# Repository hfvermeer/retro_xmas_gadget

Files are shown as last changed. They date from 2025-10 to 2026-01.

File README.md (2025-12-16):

# retro_xmas_gadget
An ESP32S3 based retro gaming handheld running retro-go the open source retro-go, inspired by Megazoid's design on his [CrokPocket](https://www.hackster.io/megazoid/crokpocket-a0ff83).

## Story
This year my niece and nephew, who are 8 and 10 became more aware of what I do for a job as an Embedded Systems Engineer and enthousiastic hobbyist. Each time when there is a family gathering, they ask about 'my inventions', and share with me their ideas what I could invent next. Since they are so interested and we are hosting Christmas this year, I wanted to share a Christmas activity where we can assemble an invention of their own, showing them what electronics can do and giving them a nice memory.

I have stumbled on Megazoid's [design](https://www.hackster.io/megazoid/crokpocket-a0ff83) of his original CrokPocket which I really liked, but I preferred a larger screen. I also had some leftover components such as a few hundred SDHD 4gb memory cards and a stack of 1900mah batteries that I could use for this design to cut cost. And I preferred the CP2102 over the CH340G, and connectors over soldering for the display. Thus the slightly larger CrokPocket XL was born.

Even though this DIY handheld doesn't compare to many linux based emulator machines that are out there, it can't compete to something that you have build yourself. And I actually find that the keypad feels more snappy, I much prefer the shorter throw and click. Featuring the [Retro-Go](https://github.com/ducalex/retro-go) open source firmware I think it can stand on it's own, supporting many games on NES, SNES (slow), Gameboy, Sega Master System, Mega Drive, Game Gear, Colecovision, NEX PC Engine, Atari Lynx and off course, DOOM.

## Instructions

### 1. Ordering

### 2. Soldering

### 3. Flashing

### 4. Printing

### 5. Assembly

## Bill of Materials

## Release Notes

### Changes

* Version 0.9.0
    * Initial 4-layer PCB design

* Version 1.0.0
    * Correct ESP32-S3 footprint, apply keepout area to inner layers
    * Move Screw holes to corners
    * Add Load-sharing Circuit for charging

* Version 1.1.0
    * Footprint Correction for Q3
    * Change values for thermal protection resistors, R17, R23

* Known Issues
    * Reset when unplugging USB
    * Batt voltage measurement when USB plugged in
    * Guide marking for screen
    * More Decoupling for 3.3V

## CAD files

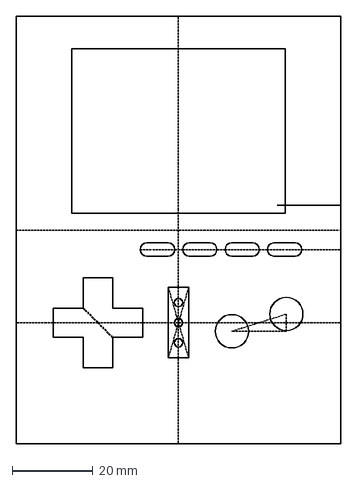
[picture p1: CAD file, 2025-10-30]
kicad/placement/Button Placement v2.dxf
80.6 x 106.0 mm

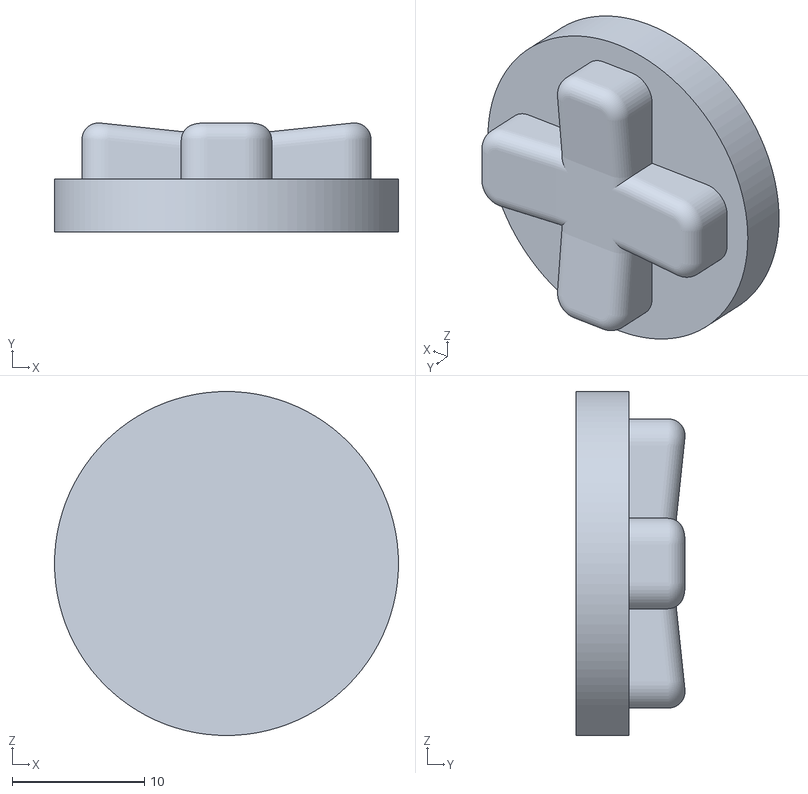
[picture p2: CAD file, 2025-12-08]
stls/v1/Thumb Button Tight.stl
26.0 x 8.25 x 26.0

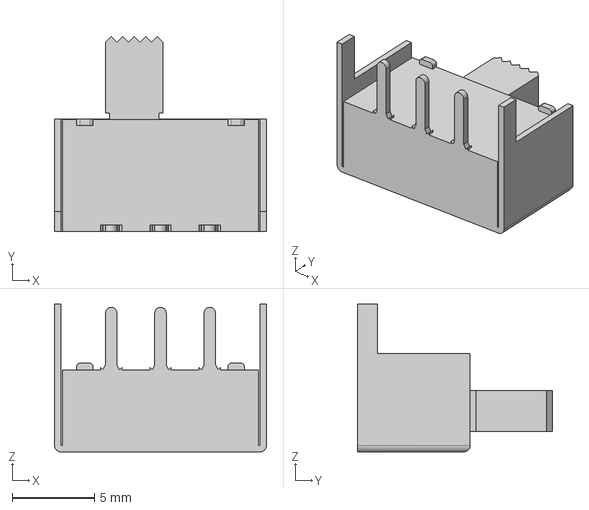
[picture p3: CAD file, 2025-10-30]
kicad/3d-models/KH-SH12F23-G6 v0.step
12.9 x 11.8 x 9.00 mm

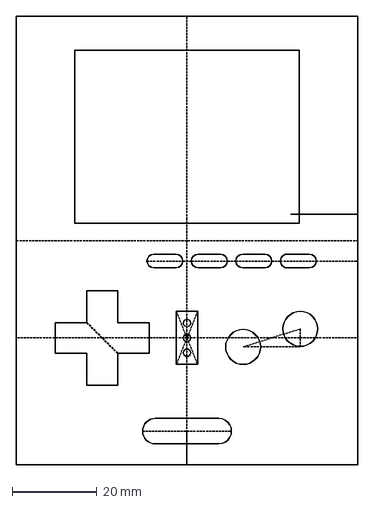
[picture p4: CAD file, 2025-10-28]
kicad/placement/Buttons.dxf
80.6 x 106.0 mm

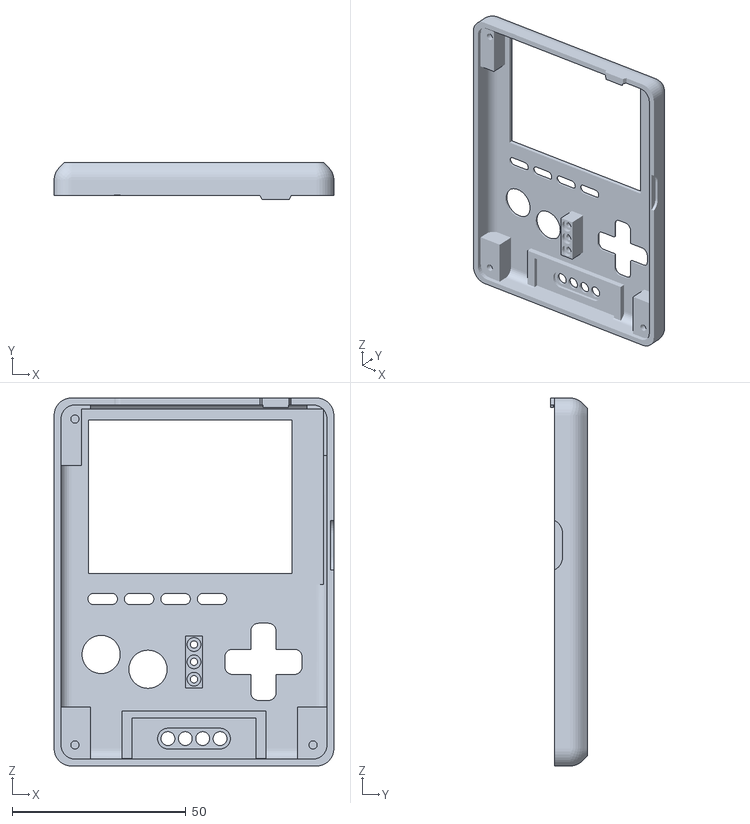
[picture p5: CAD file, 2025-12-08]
stls/v1/Front 28 inch v1.stl
80.6 x 10.8 x 106.0

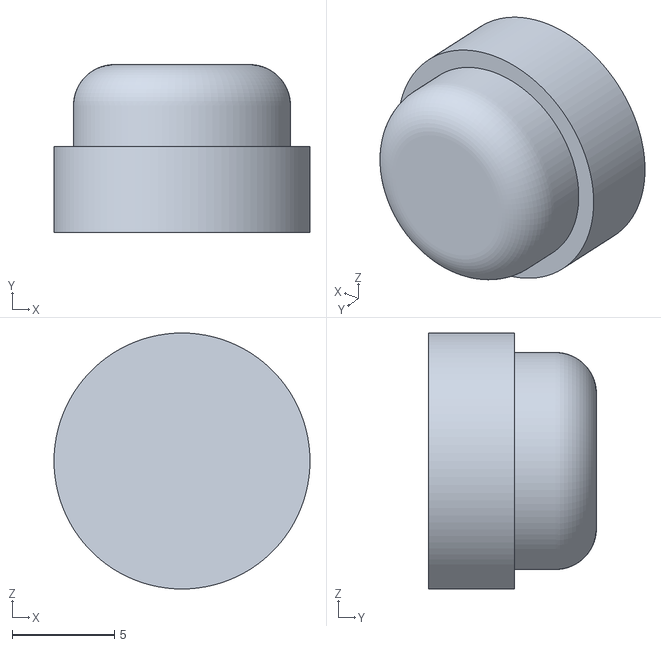
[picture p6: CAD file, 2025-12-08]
stls/v1/AB Button Tight.stl
12.5 x 8.20 x 12.5

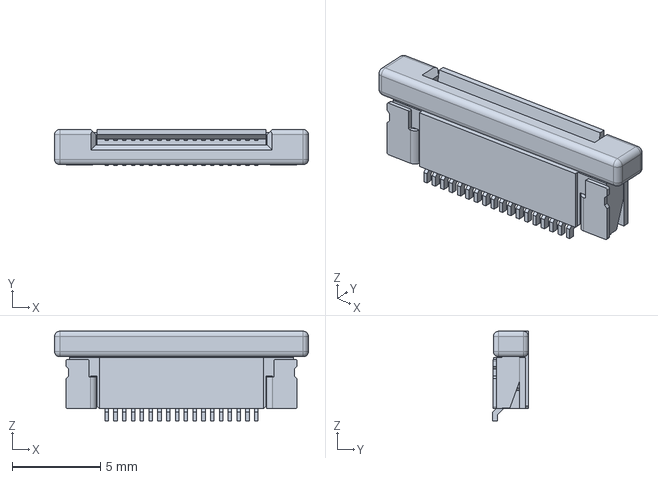
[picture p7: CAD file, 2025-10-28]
kicad/3d-models/c-1-1734839-8-c-3d.stp
14.4 x 2.05 x 5.11 mm

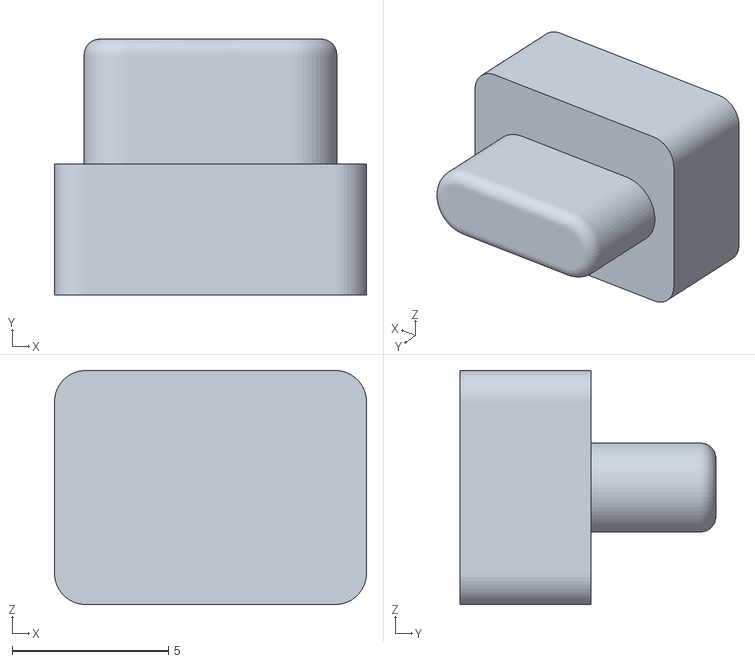
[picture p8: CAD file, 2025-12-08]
stls/v1/Function Button Tight.stl
10.00 x 8.20 x 7.50

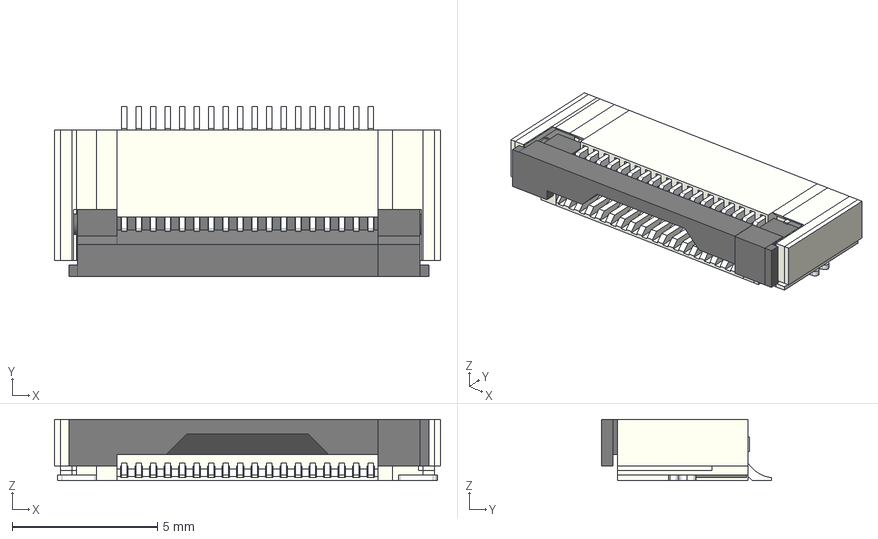
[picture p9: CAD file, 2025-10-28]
kicad/3d-models/FPC-18.stp
13.3 x 5.85 x 2.11 mm

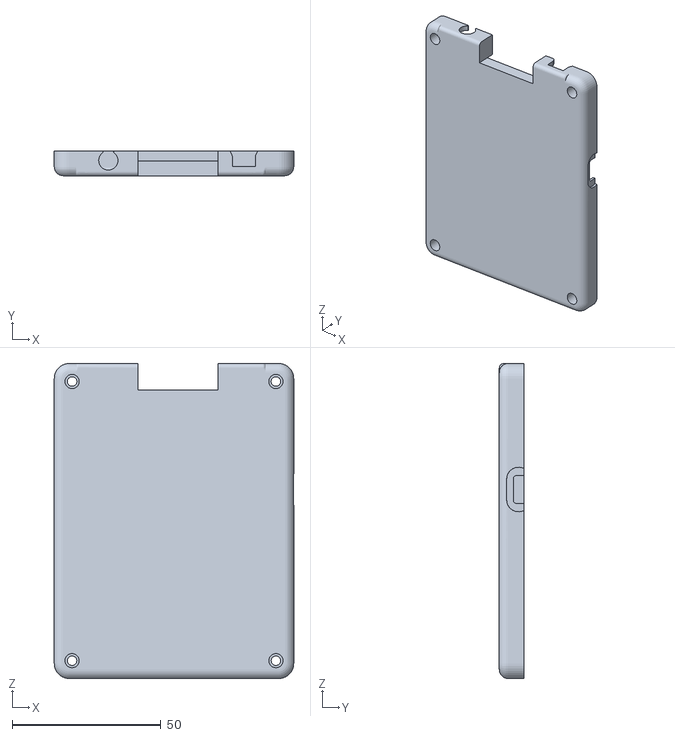
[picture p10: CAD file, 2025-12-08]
stls/v1/Back v1.stl
80.6 x 8.25 x 106.0

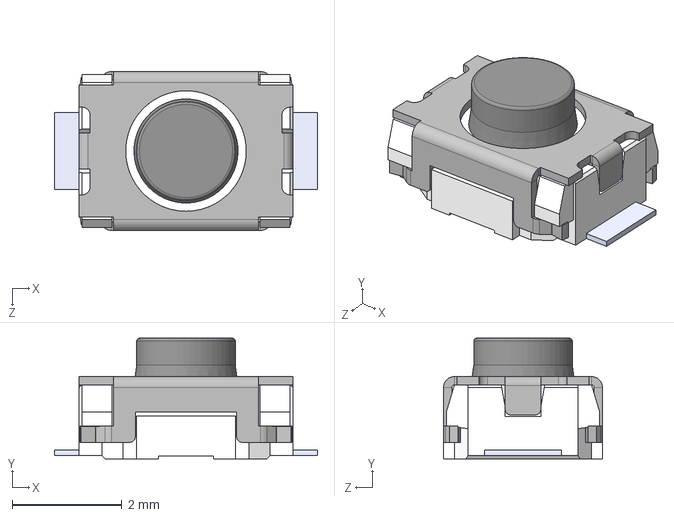
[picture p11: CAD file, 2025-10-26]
kicad/3d-models/SKRKAHE020--3DModel-STEP-56544.STEP
4.80 x 2.20 x 2.90 mm

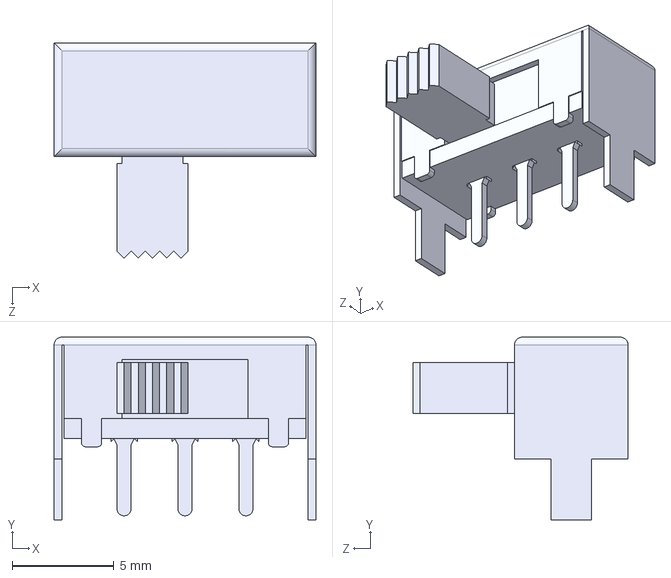
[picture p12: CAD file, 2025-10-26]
kicad/3d-models/SLW-1298856-5A-RA-N-D.STEP
12.9 x 9.00 x 10.6 mm

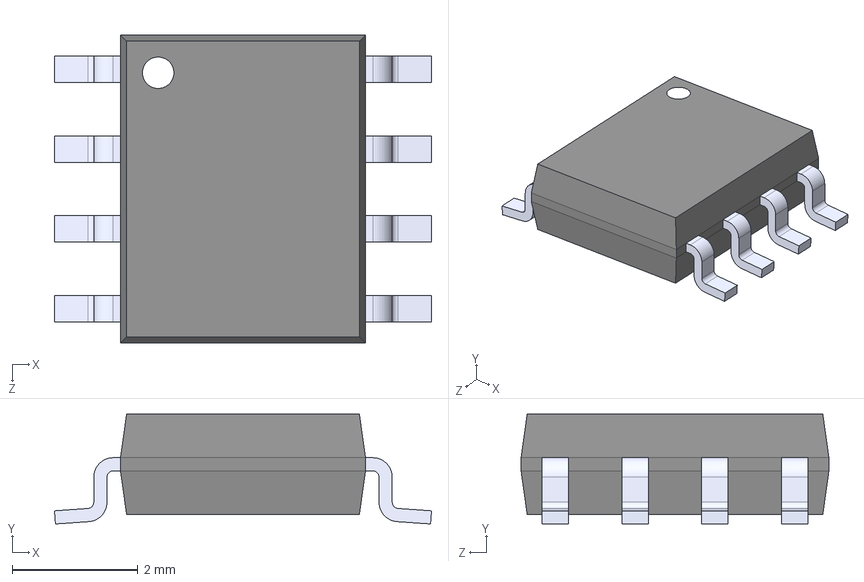
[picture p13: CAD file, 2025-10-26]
kicad/3d-models/TP4056.step
6.00 x 1.75 x 4.90 mm

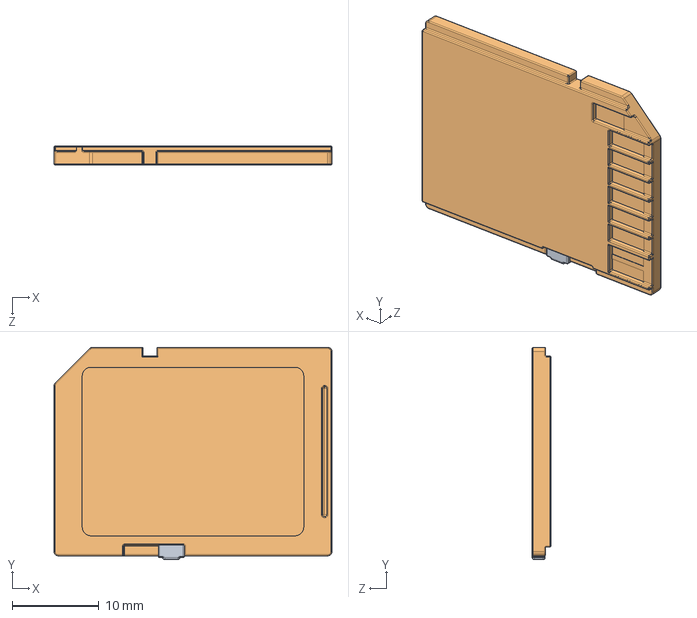
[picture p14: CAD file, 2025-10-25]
kicad/3d-models/SD Card.STEP
32.0 x 24.4 x 2.15 mm

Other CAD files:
kicad/3d-models/KB3SPRS.STEP
kicad/3d-models/10114830-10103LF.step
kicad/3d-models/10114830-10102LF.step
kicad/3d-models/2041021-4.stp

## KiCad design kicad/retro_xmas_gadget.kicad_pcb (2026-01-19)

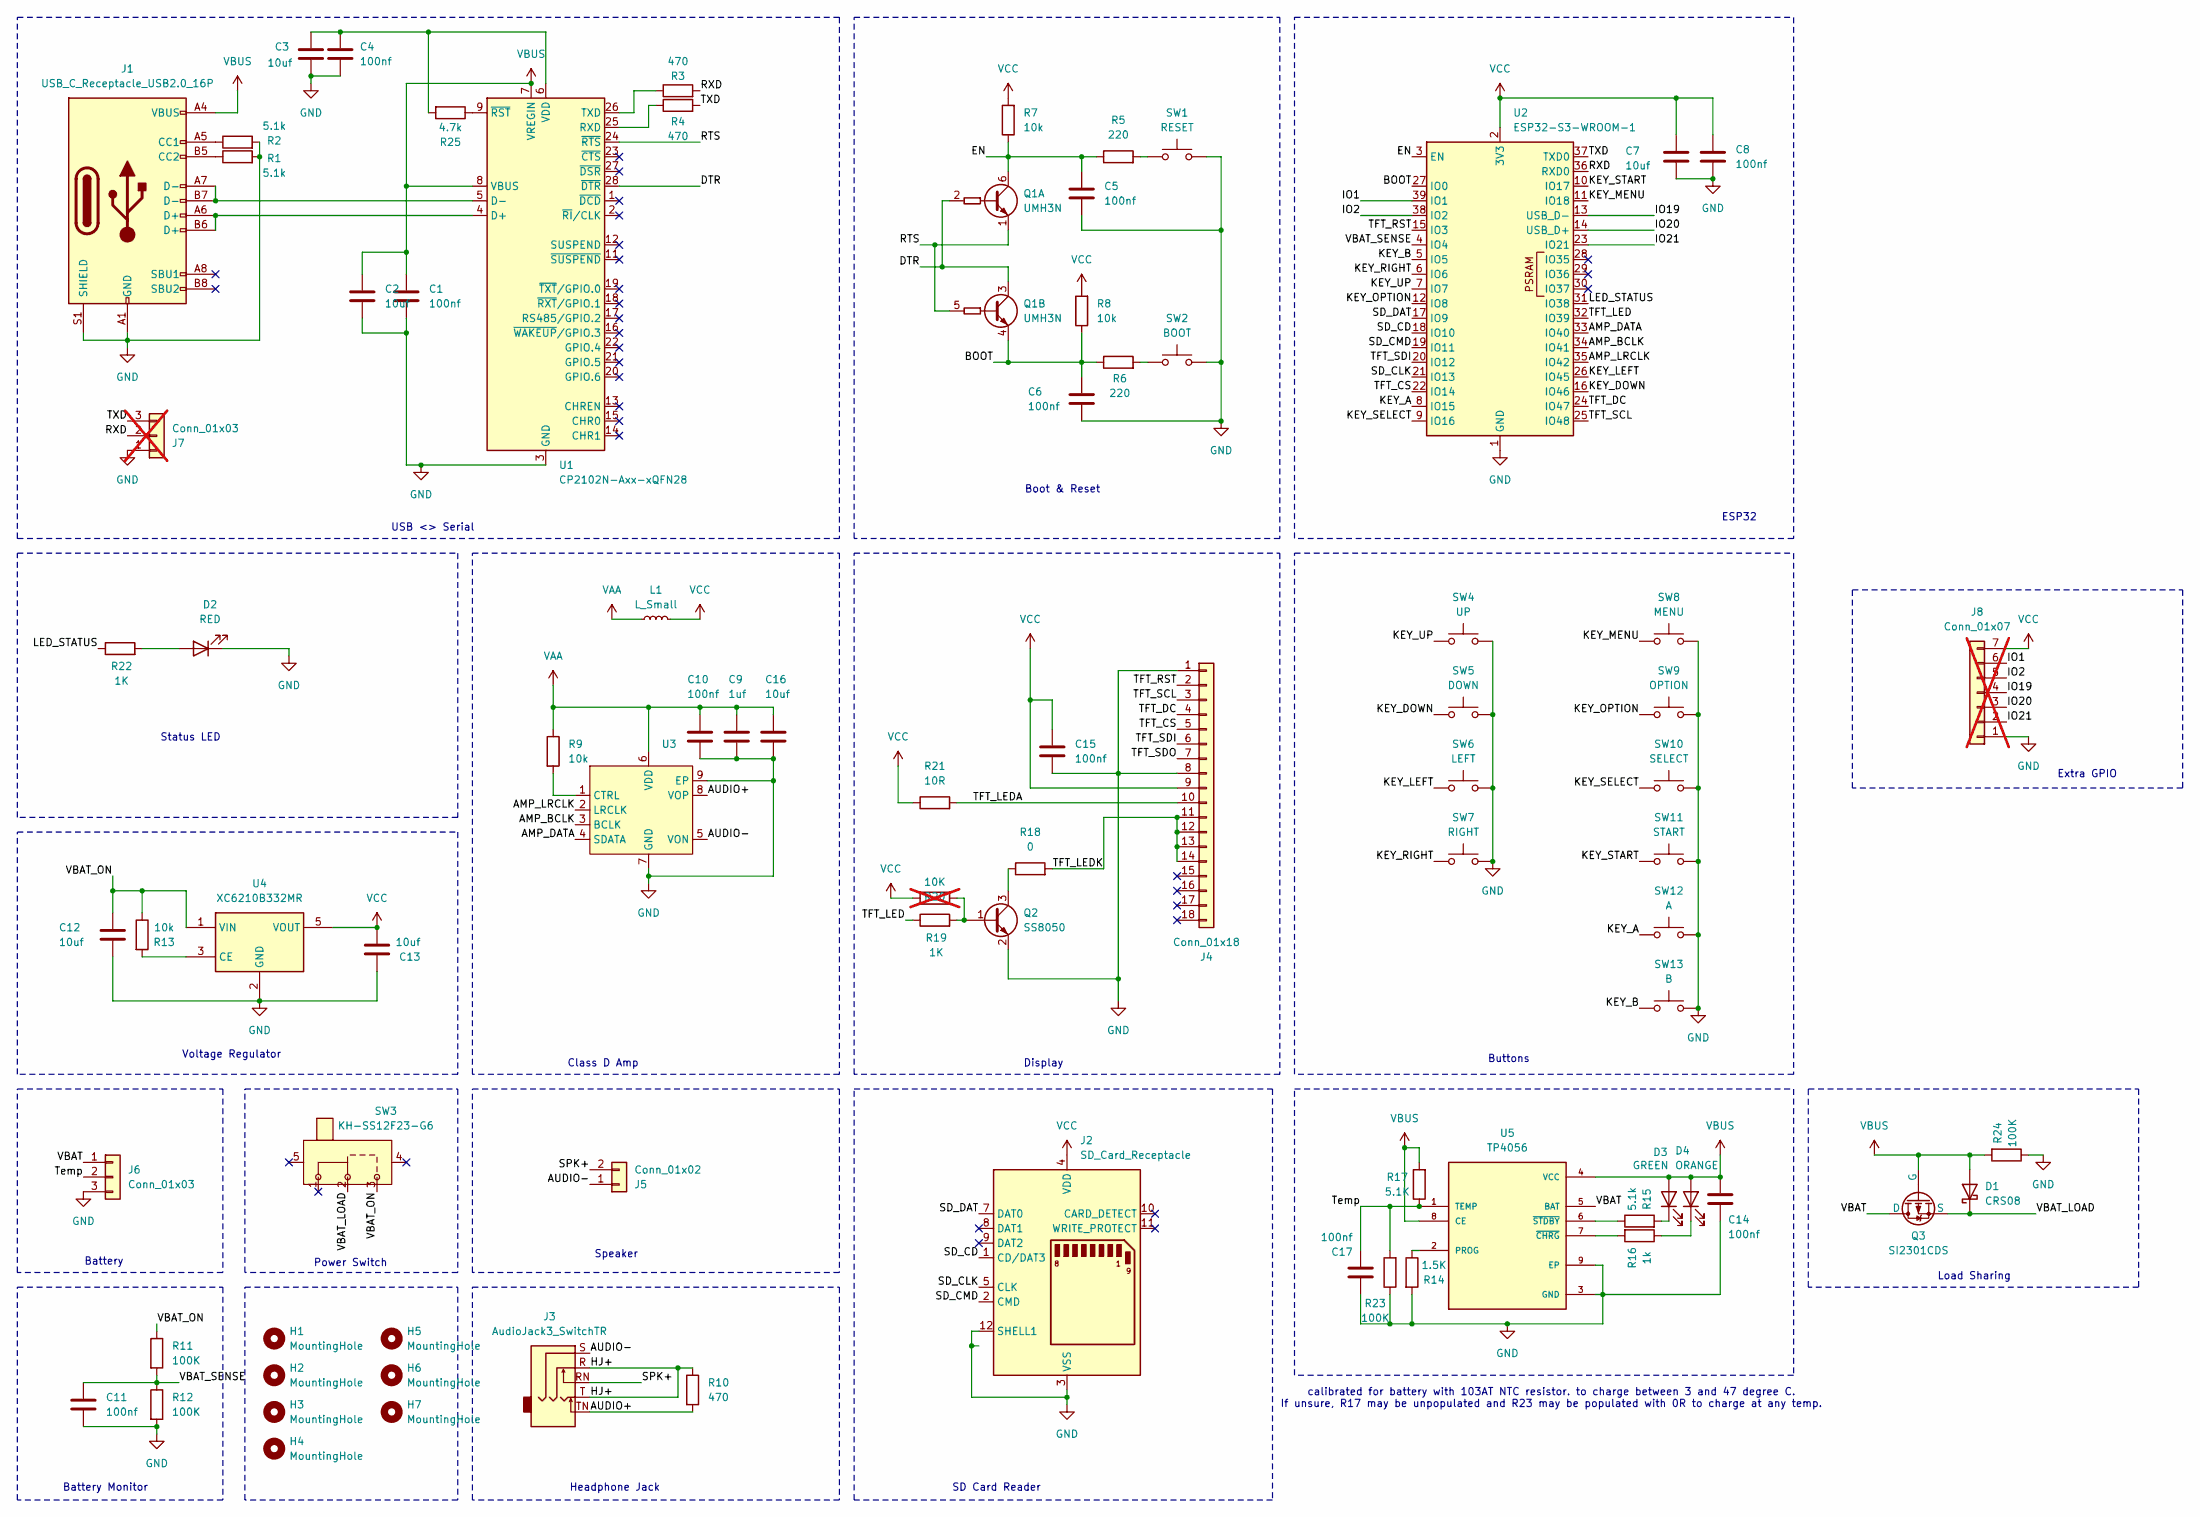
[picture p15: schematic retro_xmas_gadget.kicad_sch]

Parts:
C1, C4, C5, C6, C8, C10, C11, C14, C15, C17: 100nf; C_0603_1608Metric_Pad1.08x0.95mm_HandSolder
C2, C3, C7, C12, C13: 10uf; C_0603_1608Metric_Pad1.08x0.95mm_HandSolder
C9: 1uf; C_0603_1608Metric_Pad1.08x0.95mm_HandSolder
C16: 10uf; C_0805_2012Metric_Pad1.18x1.45mm_HandSolder
D1: CRS08; D_SOD-123
D2: RED; LED_0805_2012Metric_Pad1.15x1.40mm_HandSolder
D3: GREEN; LED_0805_2012Metric_Pad1.15x1.40mm_HandSolder
D4: ORANGE; LED_0805_2012Metric_Pad1.15x1.40mm_HandSolder
H1, H2, H3, H4: MountingHole; MountingHole_2.7mm_M2.5
H5, H6: MountingHole; MountingHole_2.5mm
H7: MountingHole; MountingHole_3.5mm
J1: USB_C_Receptacle_USB2.0_16P; USB_C_Receptacle_GCT_USB4105-xx-A_16P_TopMnt_Horizontal
J2: SD_Card_Receptacle; SD_TE_2041021
J3: AudioJack3_SwitchTR; Jack_3.5mm_Ledino_KB3SPRS_Horizontal
J4: Conn_01x18; TE_1-1734839-8_1x18-1MP_P0.5mm_Horizontal
J5: Conn_01x02; AMPHENOL_10114830-10102LF
J6: Conn_01x03; AMPHENOL_10114830-10103LF
J7: Conn_01x03; PinHeader_1x03_P2.54mm_Vertical; not fitted
J8: Conn_01x07; JST_GH_SM07B-GHS-TB_1x07-1MP_P1.25mm_Horizontal; not fitted
L1: L_Small; L_0805_2012Metric_Pad1.05x1.20mm_HandSolder
Q1: UMH3N; SOT-363_SC-70-6
Q2: SS8050; SOT-23
Q3: SI2301CDS; SOT-23_Handsoldering
R1, R2, R15: 5.1k; R_0603_1608Metric_Pad0.98x0.95mm_HandSolder
R3, R4, R10: 470; R_0603_1608Metric_Pad0.98x0.95mm_HandSolder
R5, R6: 220; R_0603_1608Metric_Pad0.98x0.95mm_HandSolder
R7, R8, R9, R13: 10k; R_0603_1608Metric_Pad0.98x0.95mm_HandSolder
R11, R12, R23, R24: 100K; R_0603_1608Metric_Pad0.98x0.95mm_HandSolder
R14: 1.5K; R_0603_1608Metric_Pad0.98x0.95mm_HandSolder
R16: 1k; R_0603_1608Metric_Pad0.98x0.95mm_HandSolder
R17: 5.1K; R_0603_1608Metric_Pad0.98x0.95mm_HandSolder
R18: 0; R_0603_1608Metric_Pad0.98x0.95mm_HandSolder
R19, R22: 1K; R_0603_1608Metric_Pad0.98x0.95mm_HandSolder
R20: 10K; R_0603_1608Metric_Pad0.98x0.95mm_HandSolder; not fitted
R21: 10R; R_0603_1608Metric_Pad0.98x0.95mm_HandSolder
R25: 4.7k; R_0603_1608Metric_Pad0.98x0.95mm_HandSolder
SW1: RESET; SW_Push_SPST_NO_Alps_SKRK
SW2: BOOT; SW_Push_SPST_NO_Alps_SKRK
SW3: KH-SS12F23-G6; SW_Slide_SPDT_Angled_CK_OS102011MA1Q
SW4: UP; SW_SPST_SKQG_WithStem
SW5: DOWN; SW_SPST_SKQG_WithStem
SW6: LEFT; SW_SPST_SKQG_WithStem
SW7: RIGHT; SW_SPST_SKQG_WithStem
SW8: MENU; SW_SPST_SKQG_WithStem
SW9: OPTION; SW_SPST_SKQG_WithStem
SW10: SELECT; SW_SPST_SKQG_WithStem
SW11: START; SW_SPST_SKQG_WithStem
SW12: A; SW_SPST_SKQG_WithStem
SW13: B; SW_SPST_SKQG_WithStem
U1: CP2102N-Axx-xQFN28; QFN-28-1EP_5x5mm_P0.5mm_EP3.35x3.35mm
U2: ESP32-S3-WROOM-1
U3: SOIC-8-1EP_3.9x4.9mm_P1.27mm_EP2.41x3.3mm_ThermalVias
U4: XC6210B332MR; SOT-23-5
U5: TP4056; SOIC-8-1EP_3.9x4.9mm_P1.27mm_EP2.41x3.3mm_ThermalVias

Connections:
/AMP_BCLK: U2.34 (IO41), U3.3 (BCLK)
/AMP_DATA: U2.33 (IO40), U3.4 (SDATA)
/AMP_LRCLK: U2.35 (IO42), U3.2 (LRCLK)
/AUDIO+: J3.TN, R10.2, U3.8 (VOP)
/AUDIO-: J3.S, J5.1, U3.5 (VON)
/BOOT: C6.1, Q1.4 (E2), R6.1, R8.1, U2.27 (IO0)
/DTR: Q1.2 (B1), Q1.3 (C2), U1.28 (~DTR)
/EN: C5.1, Q1.6 (C1), R5.1, R7.1, U2.3 (EN)
/HJ+: J3.R, J3.T, R10.1
/IO1: J8.6, U2.39 (IO1)
/IO2: J8.5, U2.38 (IO2)
/IO19: J8.4, U2.13 (USB_D-)
/IO20: J8.3, U2.14 (USB_D+)
/IO21: J8.2, U2.23 (IO21)
/KEY_A: SW12.1, U2.8 (IO15)
/KEY_B: SW13.1, U2.5 (IO5)
/KEY_DOWN: SW5.1, U2.16 (IO46)
/KEY_LEFT: SW6.1, U2.26 (IO45)
/KEY_MENU: SW8.1, U2.11 (IO18)
/KEY_OPTION: SW9.1, U2.12 (IO8)
/KEY_RIGHT: SW7.1, U2.6 (IO6)
/KEY_SELECT: SW10.1, U2.9 (IO16)
/KEY_START: SW11.1, U2.10 (IO17)
/KEY_UP: SW4.1, U2.7 (IO7)
/LED_STATUS: R22.1, U2.31 (IO38)
/RTS: Q1.1 (E1), Q1.5 (B2), U1.24 (~RTS)
/RXD: J7.2, R3.2, U2.36 (RXD0)
/SD_CD: J2.1 (CD/DAT3), U2.18 (IO10)
/SD_CLK: J2.5 (CLK), U2.21 (IO13)
/SD_CMD: J2.2 (CMD), U2.19 (IO11)
/SD_DAT: J2.7 (DAT0), U2.17 (IO9)
/SPK+: J3.RN, J5.2
/TFT_CS: J4.5, U2.22 (IO14)
/TFT_DC: J4.4, U2.24 (IO47)
/TFT_LED: R19.1, U2.32 (IO39)
/TFT_LEDA: J4.10, R21.2
/TFT_LEDK: J4.11, J4.12, J4.13, J4.14, R18.2
/TFT_RST: J4.2, U2.15 (IO3)
/TFT_SCL: J4.3, U2.25 (IO48)
/TFT_SDI: J4.6, U2.20 (IO12)
/TFT_SDO: J4.7
/TXD: J7.3, R4.2, U2.37 (TXD0)
/Temp: C17.2, J6.2, R17.1, R23.2, U5.1 (TEMP)
/VBAT: J6.1, Q3.2 (D), U5.5 (BAT)
/VBAT_LOAD: D1.1 (K), Q3.3 (S), SW3.2 (B)
/VBAT_ON: C12.2, R11.1, R13.1, SW3.3 (C), U4.1 (VIN)
/VBAT_SENSE: C11.1, R11.2, R12.1, U2.4 (IO4)
GND: C1.2, C2.2, C3.2, C4.2, C5.2, C6.2, C7.2, C8.2, C9.2, C10.2, C11.2, C12.1, C13.2, C14.2, C15.2, C16.2, C17.1, D2.1 (K), J1.A1 (GND), J1.A12 (GND), J1.B1 (GND), J1.B12 (GND), J1.S1 (SHIELD), J2.3 (VSS), J2.6 (VSS), J2.12 (SHELL1), J4.1, J4.8, J6.3, J7.1, J8.1, Q2.2 (E), R1.2, R2.2, R12.2, R14.2, R23.1, R24.1, SW1.2, SW2.2, SW4.2, SW5.2, SW6.2, SW7.2, SW8.2, SW9.2, SW10.2, SW11.2, SW12.2, SW13.2, U1.3 (GND), U1.29 (GND), U2.1 (GND), U2.40 (GND), U2.41 (GND), U3.7 (GND), U3.9 (EP), U4.2 (GND), U5.3 (GND), U5.9 (EP)
unnamed: D2.2 (A), R22.2
unnamed: D3.1 (K), R15.2
unnamed: D4.1 (K), R16.1
unnamed: J1.A5 (CC1), R2.1
unnamed: J1.B5 (CC2), R1.1
unnamed: Q2.1 (B), R19.2, R20.1
unnamed: Q2.3 (C), R18.1
unnamed: R5.2, SW1.1
unnamed: R6.2, SW2.1
unnamed: J1.A6 (D+), J1.B6 (D+), U1.4 (D+)
unnamed: J1.A7 (D-), J1.B7 (D-), U1.5 (D-)
unnamed: R4.1, U1.25 (RXD)
unnamed: R3.1, U1.26 (TXD)
unnamed: C3.1, C4.1, R25.2, U1.6 (VDD)
unnamed: R25.1, U1.9 (~RST)
unnamed: R9.2, U3.1 (CTRL)
unnamed: R13.2, U4.3 (CE)
unnamed: R14.1, U5.2 (PROG)
unnamed: R16.2, U5.7 (~CHRG)
unnamed: R15.1, U5.6 (~STDBY)
VAA: C9.1, C10.1, C16.1, L1.1, R9.1, U3.6 (VDD)
VBUS: C1.1, C2.1, C14.1, D1.2 (A), D3.2 (A), D4.2 (A), J1.A4 (VBUS), J1.A9 (VBUS), J1.B4 (VBUS), J1.B9 (VBUS), Q3.1 (G), R17.2, R24.2, U1.7 (VREGIN), U1.8 (VBUS), U5.4 (VCC), U5.8 (CE)
VCC: C7.1, C8.1, C13.1, C15.1, J2.4 (VDD), J4.9, J8.7, L1.2, R7.2, R8.2, R20.2, R21.1, U2.2 (3V3), U4.5 (VOUT)

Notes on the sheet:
Voltage Regulator
Battery Monitor
Headphone Jack
Battery
Status LED
ESP32
Load Sharing
Display
Speaker
USB <> Serial
Boot & Reset
Class D Amp
SD Card Reader
Buttons
Extra GPIO
Power Switch
calibrated for battery with 103AT NTC resistor. to charge between 3 and 47 degree C. If unsure, R17 may be unpopulated and R23 may be populated with 0R to charge at any temp.

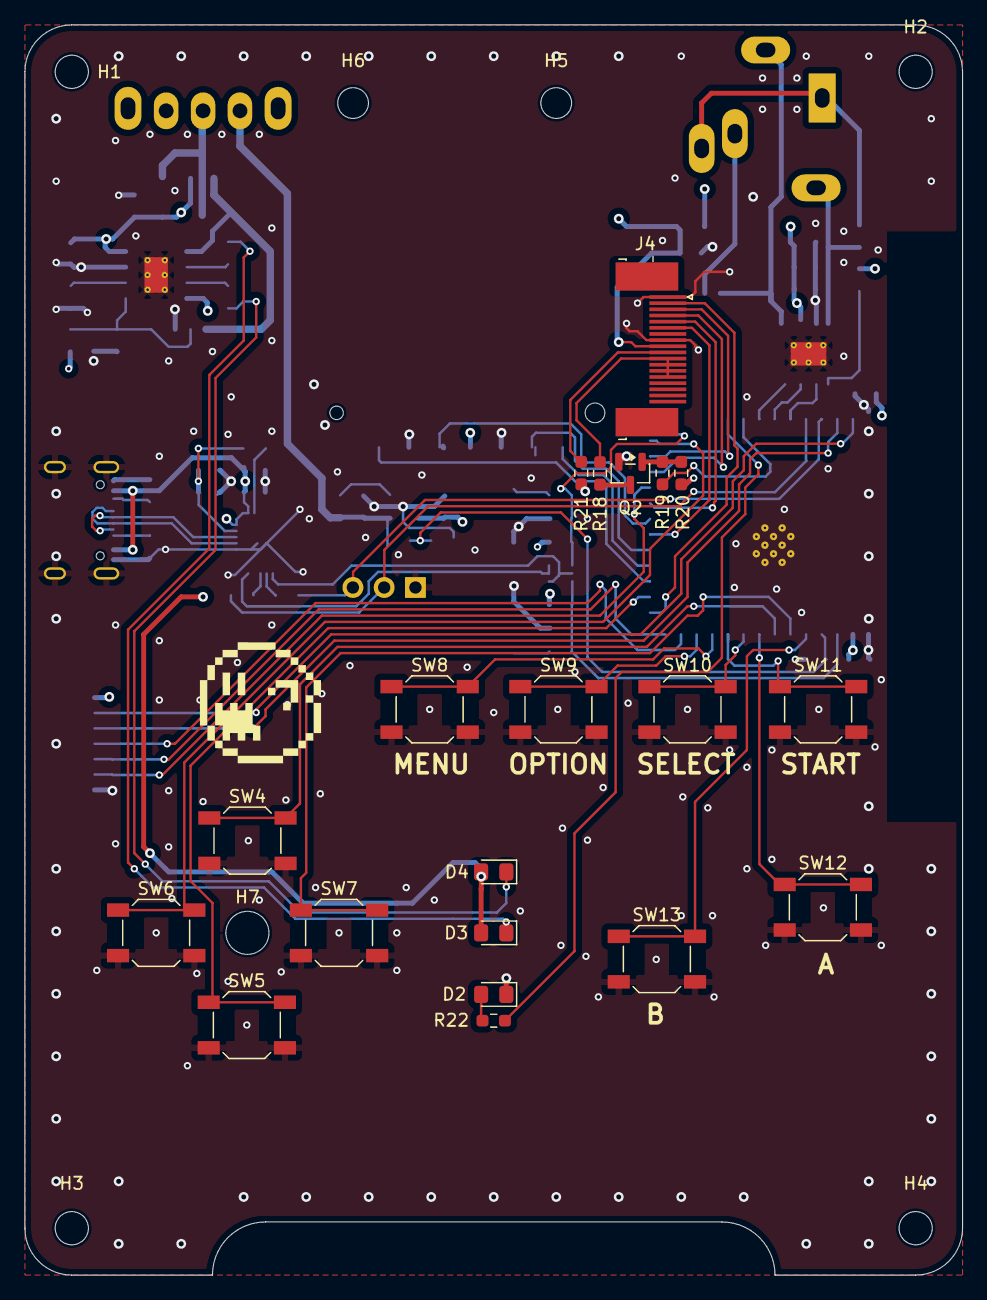
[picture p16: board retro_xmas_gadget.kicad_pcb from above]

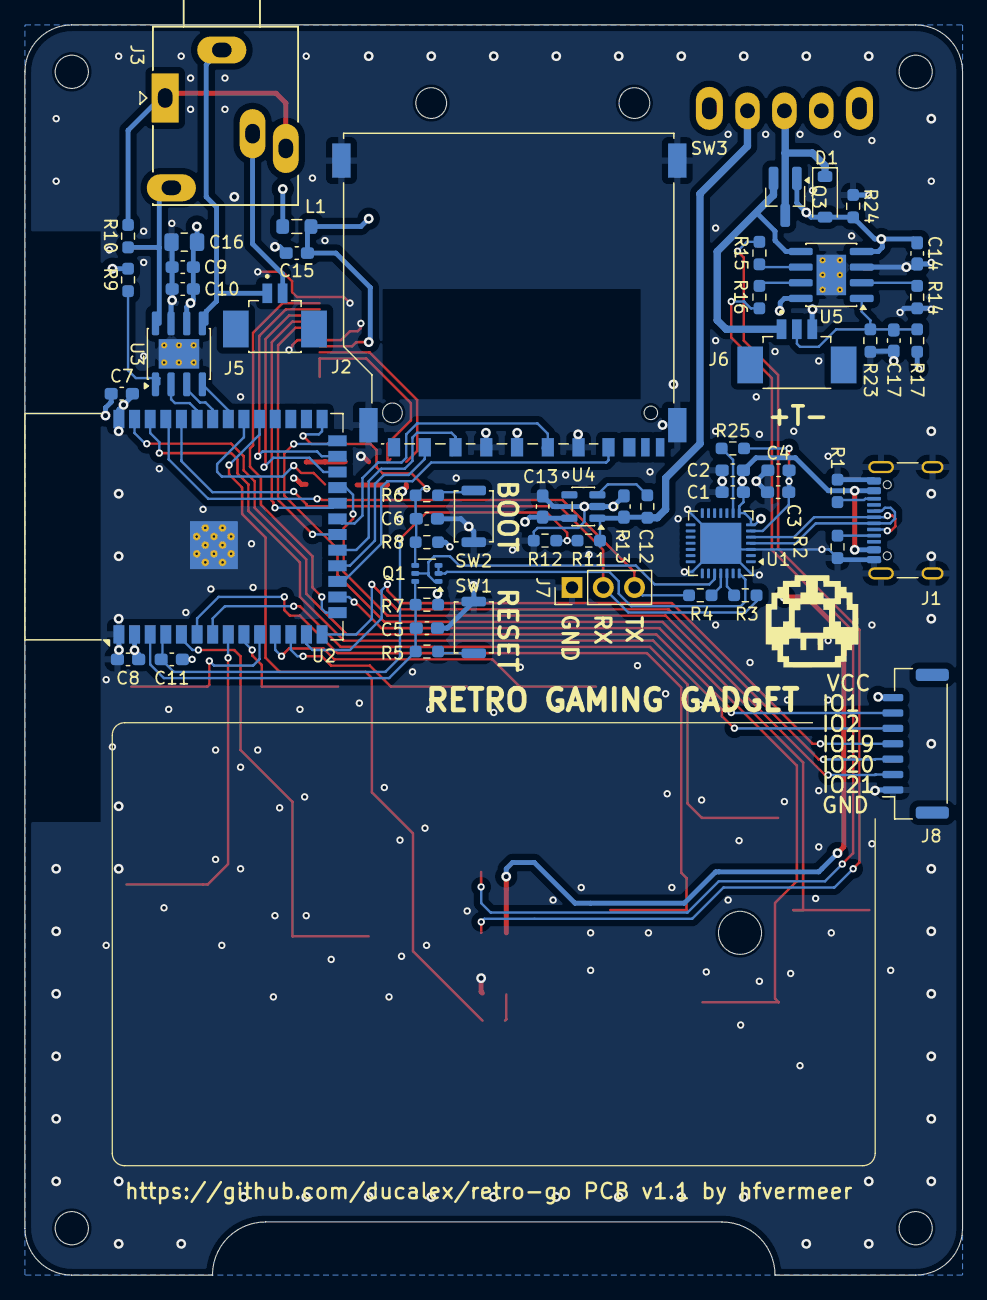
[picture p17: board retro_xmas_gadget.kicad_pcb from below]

Board: 4 copper layers, 76.2 x 101.6 mm, 83 parts (56 on the bottom side), 70 nets.

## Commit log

2025-10-25 kicad project
    [retro_xmas_gadget.kicad_pcb, retro_xmas_gadget.kicad_sch]
2025-10-25 initial schematic and board layoujt wip
    [2041021-4.stp, KB3SPRS.STEP, SD Card.STEP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]
2025-10-26 complete most of design
    [SKRKAHE020--3DModel-STEP-56544.STEP, SLW-1298856-5A-RA-N-D.STEP, TP4056.step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]
2025-10-26 initial board layout
    [retro_xmas_gadget.kicad_pcb, retro_xmas_gadget.kicad_sch]
2025-10-27 button positioning and routing
    [retro_xmas_gadget.kicad_pcb, retro_xmas_gadget.kicad_sch]
2025-10-27 moar stitching
    [retro_xmas_gadget.kicad_pcb]
2025-10-27 some DRC
    [retro_xmas_gadget.kicad_pcb]
2025-10-27 change to 4 layer pcb
    [retro_xmas_gadget.kicad_pcb, retro_xmas_gadget.kicad_sch]
2025-10-28 adjustments with 3d model
    [Buttons.dxf, FPC-18.stp, c-1-1734839-8-c-3d.stp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]
2025-10-28 baby progress
    [retro_xmas_gadget.kicad_pcb]
2025-10-28 mayor checks
    [retro_xmas_gadget.kicad_pcb, retro_xmas_gadget.kicad_sch]
2025-10-29 almost complete
    [retro_xmas_gadget.kicad_pcb, retro_xmas_gadget.kicad_sch]
2025-10-29 run down checking points
    [retro_xmas_gadget.kicad_pcb, retro_xmas_gadget.kicad_sch]
2025-10-30 final improvements and checks
    [10114830-10102LF.step, 10114830-10103LF.step, KH-SH12F23-G6 v0.step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]
2025-10-30 speaker placement
    [Button Placement v2.dxf, Front.stl, retro_xmas_gadget.kicad_pcb]
2025-10-31 final design, with decals
    [retro_xmas_gadget.kicad_pcb]
2025-11-09 3d model updates
    [retro_xmas_gadget.kicad_pcb]
2025-11-09 keep out inner layers
    [retro_xmas_gadget.kicad_pcb]
2025-11-13 improvements and corrections
    [retro_xmas_gadget.kicad_pcb, retro_xmas_gadget.kicad_sch]
2025-11-14 update charging resistor
    [retro_xmas_gadget.kicad_sch]
2025-11-14 load sharing
    [retro_xmas_gadget.kicad_pcb, retro_xmas_gadget.kicad_sch]
2025-11-15 rearrangement, updates, upgrades
    [retro_xmas_gadget.kicad_pcb]
2025-11-15 add pull up resistor to cp2102 rst
    [retro_xmas_gadget.kicad_pcb, retro_xmas_gadget.kicad_sch]
2025-11-16 design check. Gerbers
    [retro_xmas_gadget.kicad_pcb]
2025-12-08 footprint correction
    [retro_xmas_gadget.kicad_pcb, retro_xmas_gadget.kicad_sch]
2025-12-08 Add STL's, Firmware
    [AB Button Tight.stl, Back v1.stl, Front 28 inch v1.stl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]
2026-01-19 component change
    [retro_xmas_gadget.kicad_pcb, retro_xmas_gadget.kicad_sch]
